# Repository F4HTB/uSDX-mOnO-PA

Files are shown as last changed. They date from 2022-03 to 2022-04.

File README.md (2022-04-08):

# uSDX-mOnO-PA
Power Amplifier for uSDX Mono.  

This is a alpha version of 10m power amplifier for uSDX mOnO.  
It will take place in the last layer of the uSDX mOnO.  

Note that it is currently in testing.  
I keep making things better.  
Currently ~10w @ 28mhz with harmonics below 46dbc.  

The simulation folder contains an LTspice equivalent.  

Please read the notes in the diagram.  

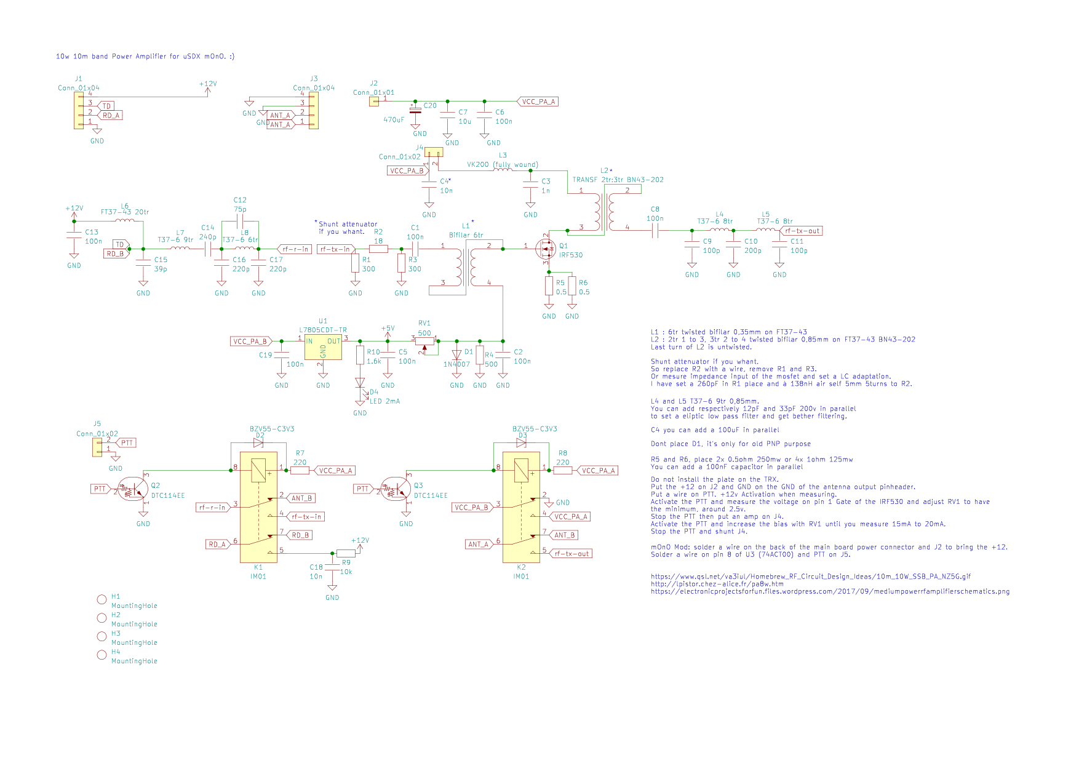
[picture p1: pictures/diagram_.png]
diagram
  

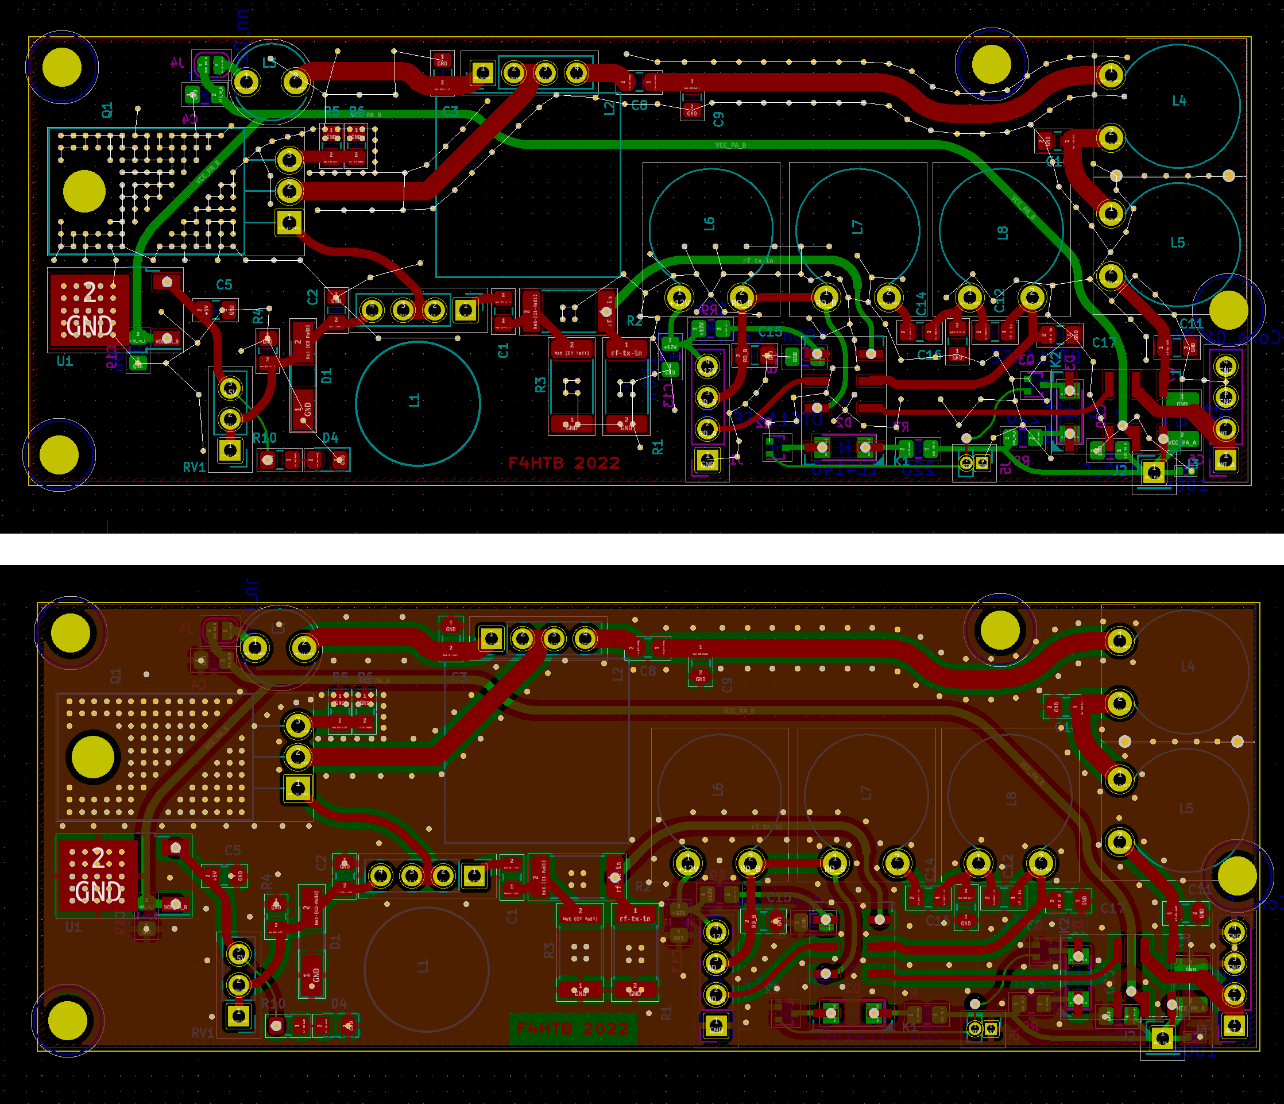
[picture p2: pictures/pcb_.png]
pcb
  

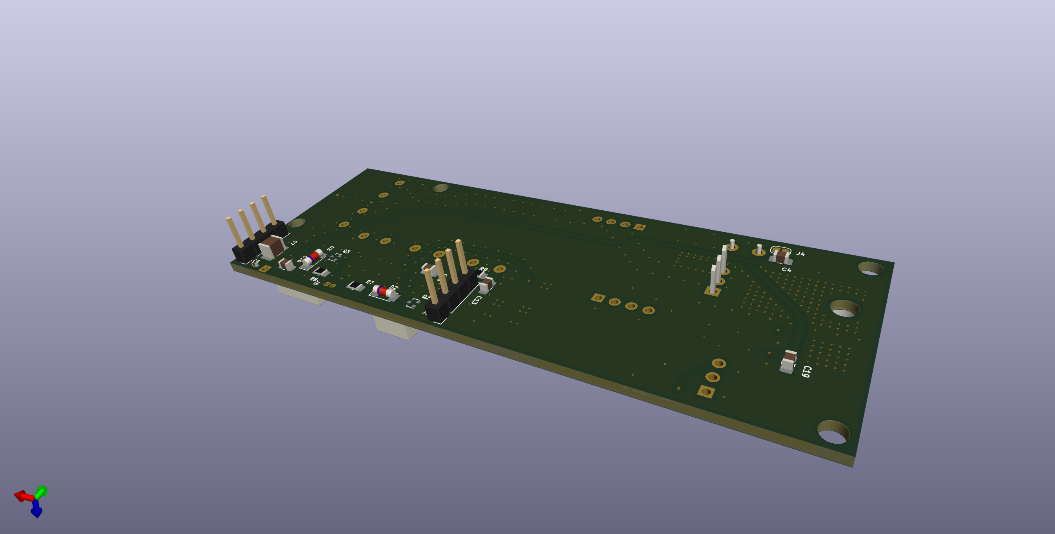
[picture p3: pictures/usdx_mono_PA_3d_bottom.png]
3d_bottom
  

3d_top  

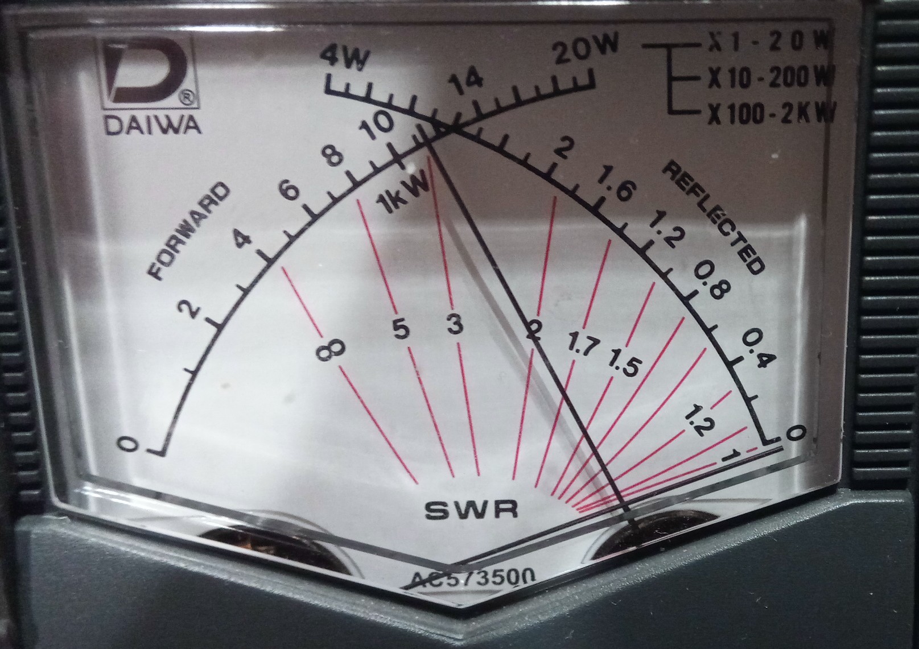
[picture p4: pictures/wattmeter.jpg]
  

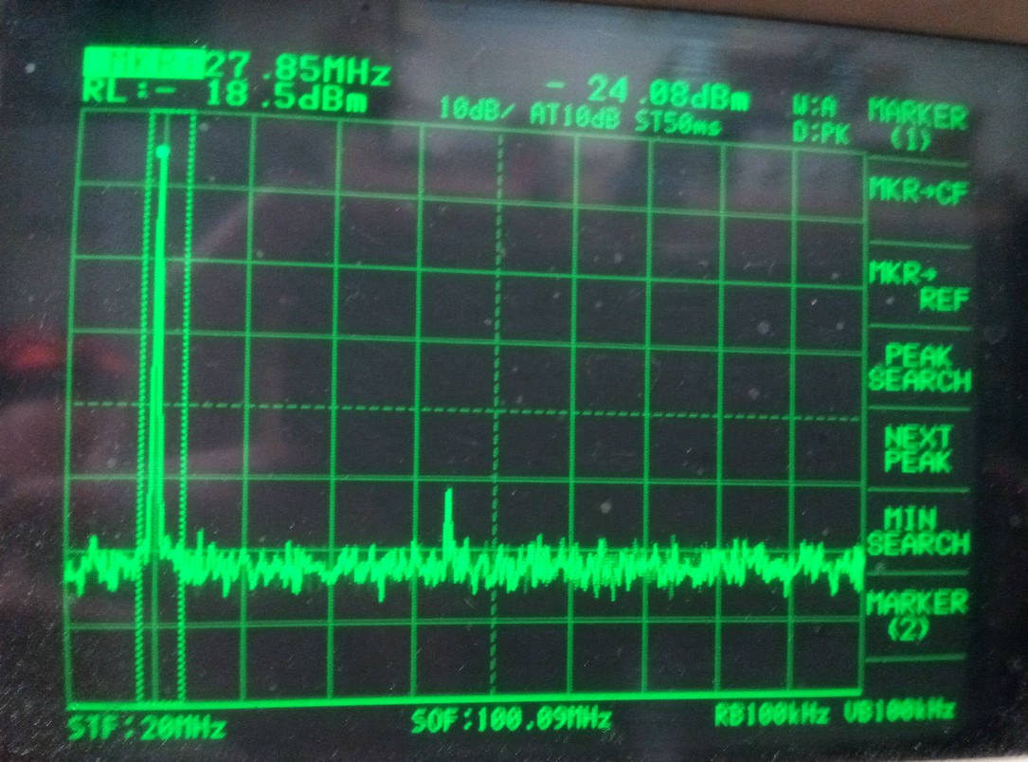
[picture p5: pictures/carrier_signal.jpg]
  

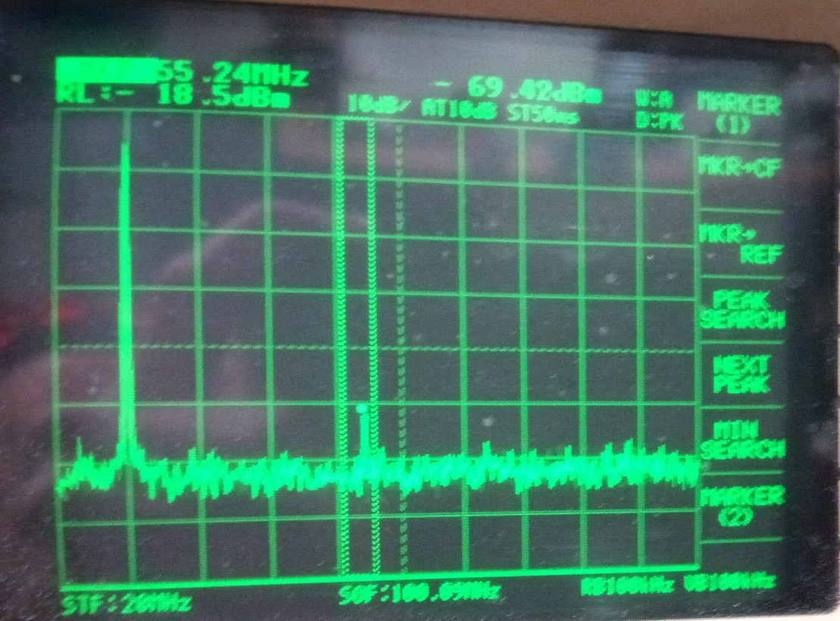
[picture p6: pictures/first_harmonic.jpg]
  

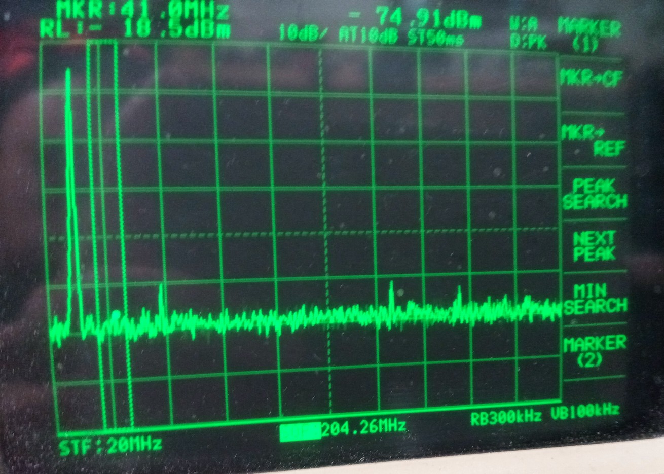
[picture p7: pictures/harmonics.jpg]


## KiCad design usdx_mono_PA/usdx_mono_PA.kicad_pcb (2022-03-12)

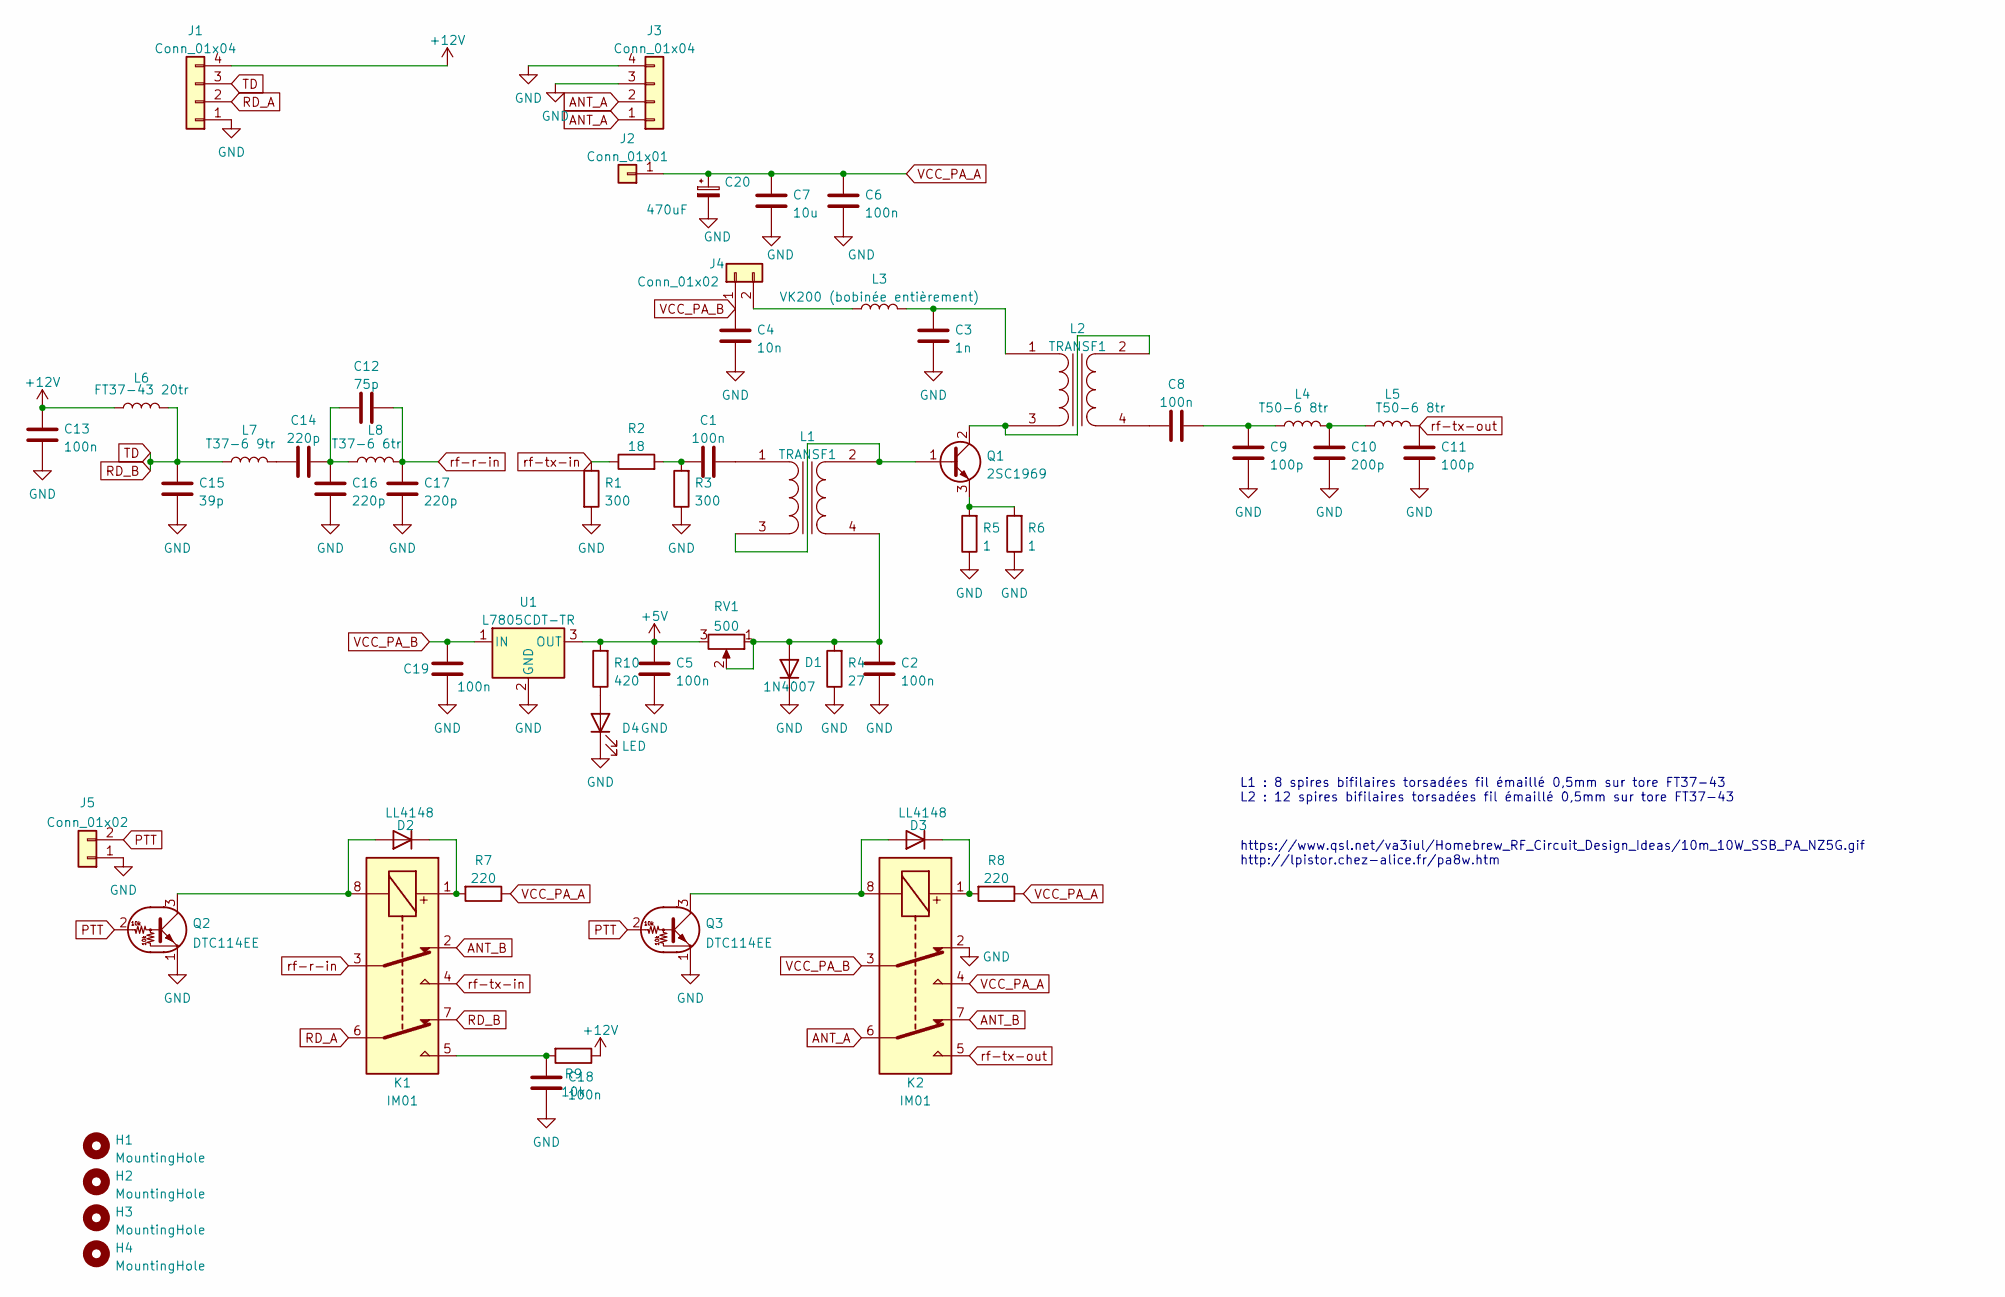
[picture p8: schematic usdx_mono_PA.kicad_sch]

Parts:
C1, C2, C5, C8, C13, C18, C19: 100n; C_0805_2012Metric_Pad1.18x1.45mm_HandSolder
C3: 1n; C_0805_2012Metric_Pad1.18x1.45mm_HandSolder
C4: 10n; C_0805_2012Metric_Pad1.18x1.45mm_HandSolder
C6: 100n; C_0402_1005Metric
C7: 10u; C_1210_3225Metric_Pad1.33x2.70mm_HandSolder
C9, C11: 100p; C_0805_2012Metric_Pad1.18x1.45mm_HandSolder
C10: 200p; C_0805_2012Metric_Pad1.18x1.45mm_HandSolder
C12: 75p; C_0805_2012Metric_Pad1.18x1.45mm_HandSolder
C14, C16, C17: 220p; C_0805_2012Metric_Pad1.18x1.45mm_HandSolder
C15: 39p; C_0805_2012Metric_Pad1.18x1.45mm_HandSolder
C20: 470uF; C_0805_2012Metric_Pad1.18x1.45mm_HandSolder
D1: 1N4007; D_MiniMELF_Handsoldering
D2, D3: LL4148; D_MiniMELF
D4: LED; LED_0805_2012Metric_Pad1.15x1.40mm_HandSolder
H1, H2, H3, H4: MountingHole; MountingHole_3.2mm_M3_ISO14580
J1, J3: Conn_01x04; PinHeader_1x04_P2.54mm_Vertical
J2: Conn_01x01; PinHeader_1x01_P2.54mm_Vertical
J4: Conn_01x02; SolderJumper-2_P1.3mm_Open_RoundedPad1.0x1.5mm
J5: Conn_01x02; PinHeader_1x02_P1.27mm_Vertical
K1, K2: IM01; Relay_DPDT_AXICOM_IMSeries_JLeg
L1, L2: TRANSF1; PinHeader_1x04_P2.54mm_Vertical
L3: VK200 (bobinée entièrement); L_Radial_D6.0mm_P4.00mm
L4, L5: T50-6 8tr; FT37-XX
L6: FT37-43 20tr; FT37-XX
L7: T37-6 9tr; FT37-XX
L8: T37-6 6tr; FT37-XX
Q1: 2SC1969; TO-220-3_Horizontal_TabDown
Q2, Q3: DTC114EE
R1, R3: 300; R_2512_6332Metric_Pad1.40x3.35mm_HandSolder
R2: 18; R_2512_6332Metric_Pad1.40x3.35mm_HandSolder
R4: 27; R_0805_2012Metric_Pad1.20x1.40mm_HandSolder
R5, R6: 1; R_0805_2012Metric_Pad1.20x1.40mm_HandSolder
R7, R8: 220; R_0805_2012Metric_Pad1.20x1.40mm_HandSolder
R9: 10k; R_0805_2012Metric_Pad1.20x1.40mm_HandSolder
R10: 420; R_0805_2012Metric_Pad1.20x1.40mm_HandSolder
RV1: 500; PinHeader_1x03_P2.54mm_Vertical
U1: L7805CDT-TR; TO-252-2

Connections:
+5V: C5.2, R10.2, RV1.3, U1.3 (OUT)
+12V: C13.2, J1.4, L6.1, R9.1
ANT_A: J3.1, J3.2, K2.6
ANT_B: K1.2, K2.7
GND: C2.1, C3.1, C4.1, C5.1, C6.1, C7.1, C9.2, C10.2, C11.2, C13.1, C15.1, C16.1, C17.1, C18.1, C19.1, C20.2, D1.1 (K), D4.1 (K), J1.1, J3.3, J3.4, J5.1, K2.2, Q2.1 (E), Q3.1 (E), R1.2, R3.1, R4.1, R5.1, R6.1, U1.2 (GND)
unnamed: C1.1, R2.2, R3.2
unnamed: C1.2, L1.1
unnamed: C2.2, D1.2 (A), L1.4, R4.2, RV1.1, RV1.2
unnamed: C3.2, L2.1, L3.2
unnamed: C8.1, C9.1, L4.1
unnamed: C8.2, L2.4
unnamed: C10.1, L4.2, L5.1
unnamed: C12.2, C14.1, C16.2, L8.1
unnamed: C14.2, L7.2
unnamed: C18.2, K1.5, R9.2
unnamed: D2.1 (K), K1.1, R7.2
unnamed: D2.2 (A), K1.8, Q2.3 (C)
unnamed: D3.1 (K), K2.1, R8.2
unnamed: D3.2 (A), K2.8, Q3.3 (C)
unnamed: D4.2 (A), R10.1
unnamed: J4.2, L3.1
unnamed: L1.2, L1.3, Q1.1 (B)
unnamed: L2.2, L2.3, Q1.2 (C)
unnamed: Q1.3 (E), R5.2, R6.2
PTT: J5.2, Q2.2 (B), Q3.2 (B)
RD_A: J1.2, K1.6
RD_B: C15.2, J1.3, K1.7, L6.2, L7.1
VCC_PA_A: C6.2, C7.2, C20.1, J2.1, K2.4, R7.1, R8.1
VCC_PA_B: C4.2, C19.2, J4.1, K2.3, U1.1 (IN)
rf-r-in: C12.1, C17.2, K1.3, L8.2
rf-tx-in: K1.4, R1.1, R2.1
rf-tx-out: C11.1, K2.5, L5.2

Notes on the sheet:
L1 : 8 spires bifilaires torsadées fil émaillé 0,5mm sur tore FT37-43 L2 : 12 spires bifilaires torsadées fil émaillé 0,5mm sur tore FT37-43
https://www.qsl.net/va3iul/Homebrew_RF_Circuit_Design_Ideas/10m_10W_SSB_PA_NZ5G.gif http://lpistor.chez-alice.fr/pa8w.htm

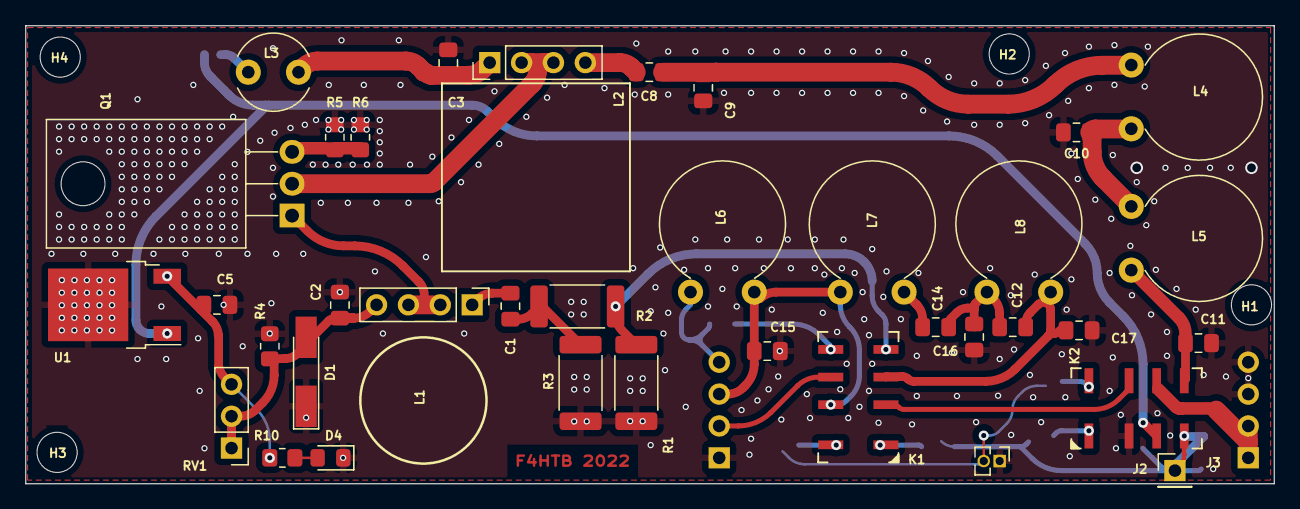
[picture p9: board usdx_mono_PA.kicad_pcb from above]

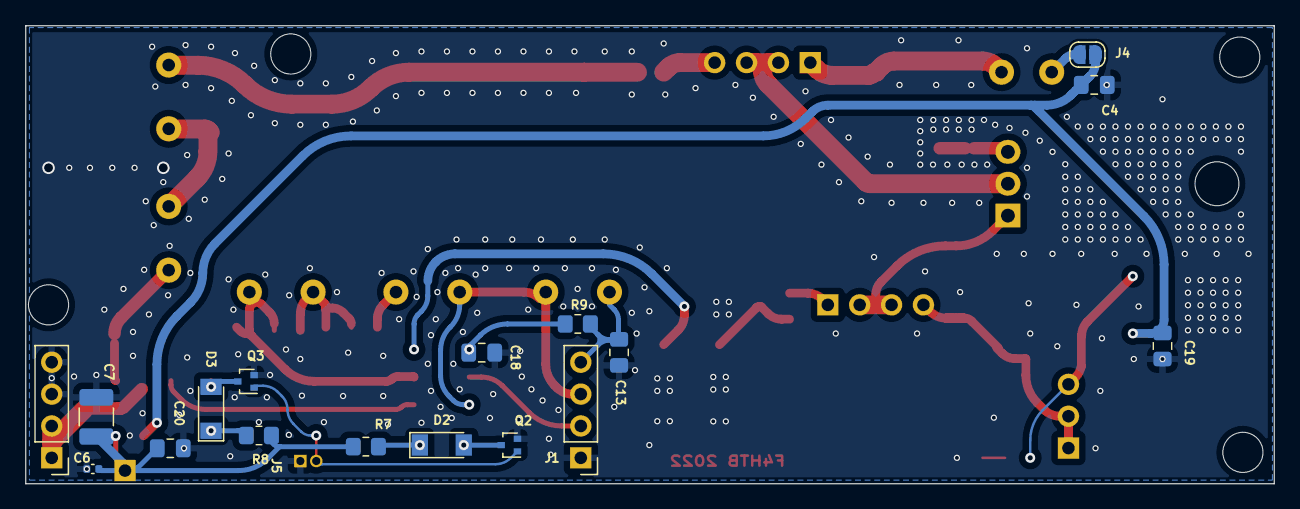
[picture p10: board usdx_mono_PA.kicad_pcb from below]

Board: 2 copper layers, 99.5 x 36.5 mm, 58 parts (17 on the bottom side), 32 nets.

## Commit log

2022-03-11 add mods
    [usdx_mono_PA.kicad_pcb]
2022-03-11 add mods on pcb
    [usdx_mono_PA.kicad_pcb]
2022-04-07 add mods and simulation files
    [usdx_mono_PA.kicad_sch]
2022-04-08 add measures and eliptic low pass filter modifications
    [usdx_mono_PA.kicad_sch]
